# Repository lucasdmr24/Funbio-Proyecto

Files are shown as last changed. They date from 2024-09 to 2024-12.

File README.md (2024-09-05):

¡Bienvenido al repositorio del grupo 4 del horario B403 de Fundamentos de Biondiseño!

Integrantes:
- **Lucas Daniel Mendoza Ramos** (Rol: Coordinador General y GitHub), estudiante de 4to ciclo de Ingeniería Biomédica interesado en desarrollo de equipos médicos e investigación. Descripción del rol: Organizar y gestionar reuniones grupales y documentos; gestión principal del repositorio de github así como la organización de tareas e información para el producto a deseñar.

  Foto Lucas (1)

- **Massiel Melisa Badillo Aguayo** (Rol: Diseño 3D y Investigación), estudiante de 4to ciclo de Ingeniería Biomédica interesada en ingeniería de tejidos y rehabilitación de pacietes. Descripción del rol: Plasmar la propuesta de solución grupal en un programa que permita su modelamiento 3D para una posterior impresión o ensamblamiento. 

  massiel foto (1)

- **Pablo Emilio Parra Valer** (Rol: Prototipado Electrónico y Actualización del Git), estudiante de 4to ciclo de Ingeniería Biomédica interesado en diseño de prótesis y desarrollo de equipos médicos. Descripción del rol: Actualizar constantemente el repositorio por medio de github; gestionar el trabajo necesario en el ámbito electrónico para su implementación en el diseño 3D.
  
  parra foto

- **Ariana Valentina Ninanya Cruz** ( Rol: Manufactura Digital y Investigación), estudiante de 4to ciclo de Ingeniería Biomédica con principal interés en la gestión de biomateriales para la producción de prótesis de rehabilitación. Descripción del rol: Gestión de materiales necesarios para la el ensamble del prototipo, encargada principal del proceso de impresión y ensamble.

  ariana foto (1)

- **Maria Teresa Mone Vilchez** (Rol: Diseño Electrónico y Redacción), estudiante de 4to ciclo de Ingeniería Biomédica interesada principalmente en ingeniería clínica y rehabilitación. Descripción del rol: Trabajo dentro de la programación del código para el circuito electrónico y funcionabilidad del mismo en una etapa posterior. 

  tere foto (1)

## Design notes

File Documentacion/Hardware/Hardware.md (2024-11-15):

*Planos case MPU superior e inferior:*

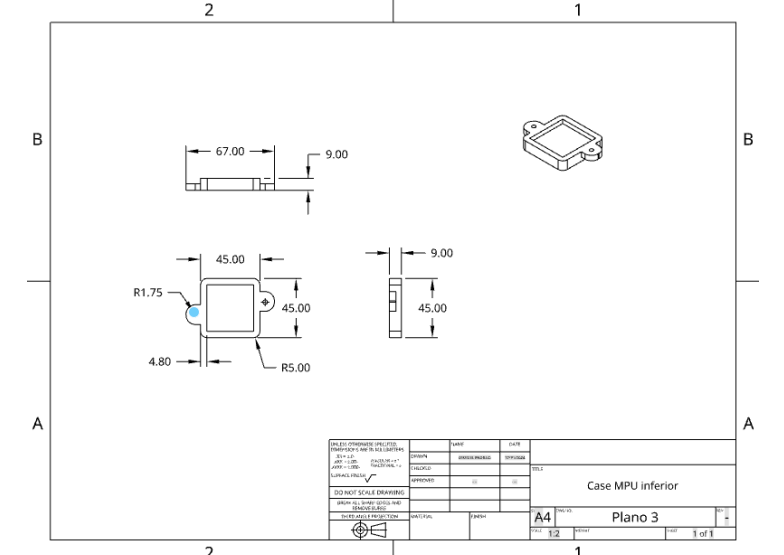
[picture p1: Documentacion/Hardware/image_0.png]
image alt text


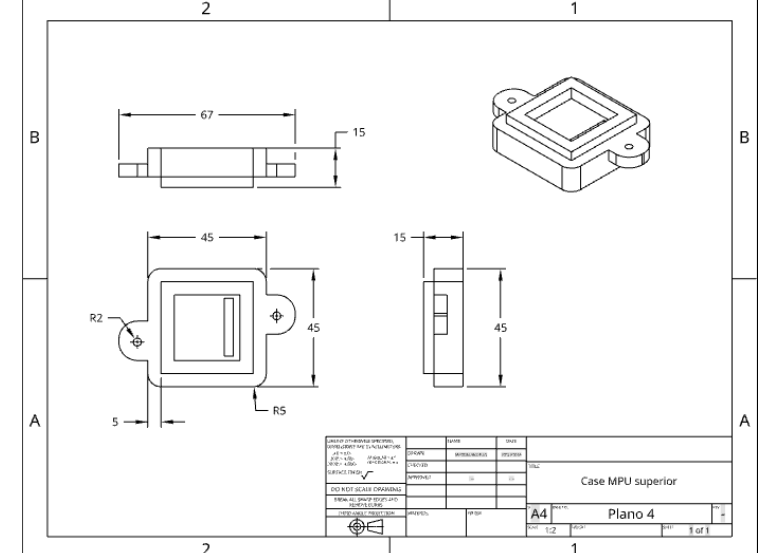
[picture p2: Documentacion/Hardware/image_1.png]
image alt text


*Planos para el case de los demás componentes electrónicos:*

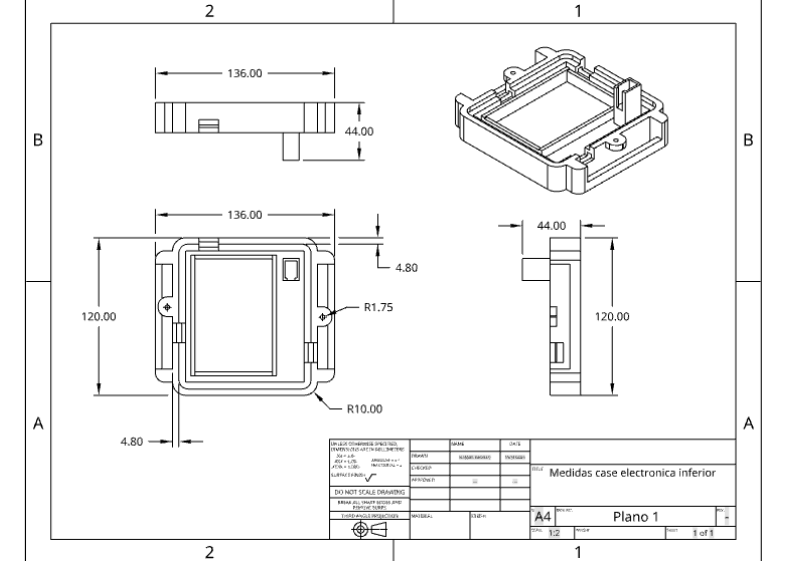
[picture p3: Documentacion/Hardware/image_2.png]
image alt text


image alt text

*Plano para case del portapila:*

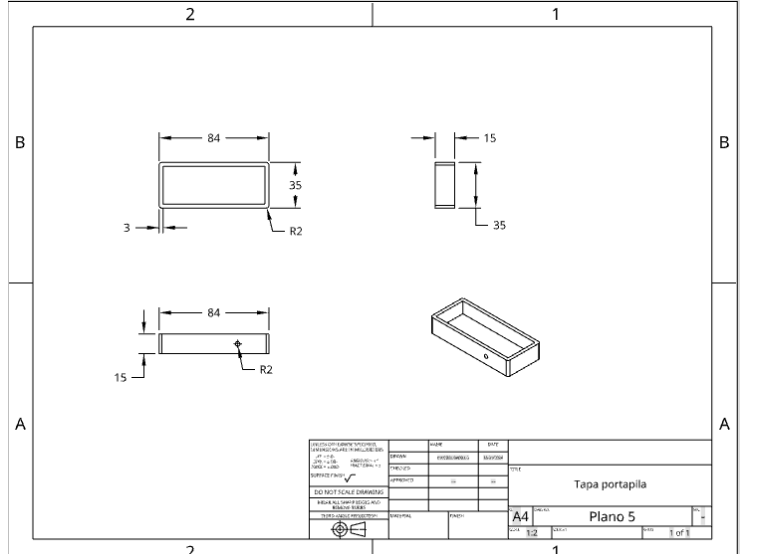
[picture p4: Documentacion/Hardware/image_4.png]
image alt text


*Ensamble:*

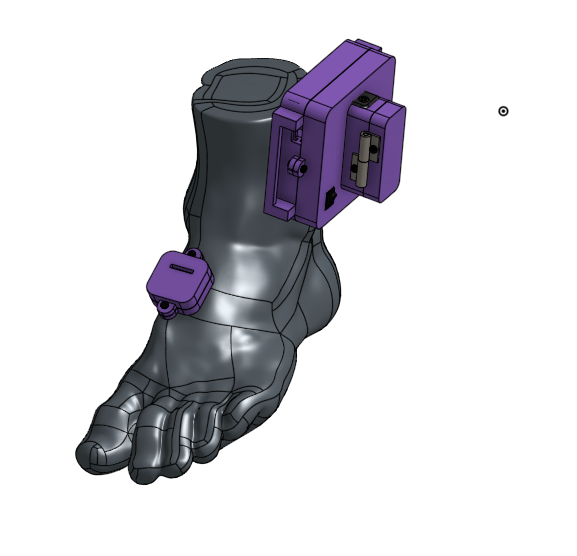
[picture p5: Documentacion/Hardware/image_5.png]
image alt text


ONESHOPE:
[https://cad.onshape.com/documents/b59706230b3147a766a9d8ca/w/d9faae820f9fd83e4ae611a1/e/5ab465d6ad715a8f3c73b799](https://cad.onshape.com/documents/b59706230b3147a766a9d8ca/w/d9faae820f9fd83e4ae611a1/e/5ab465d6ad715a8f3c73b799)

*Esquema Electrónico *

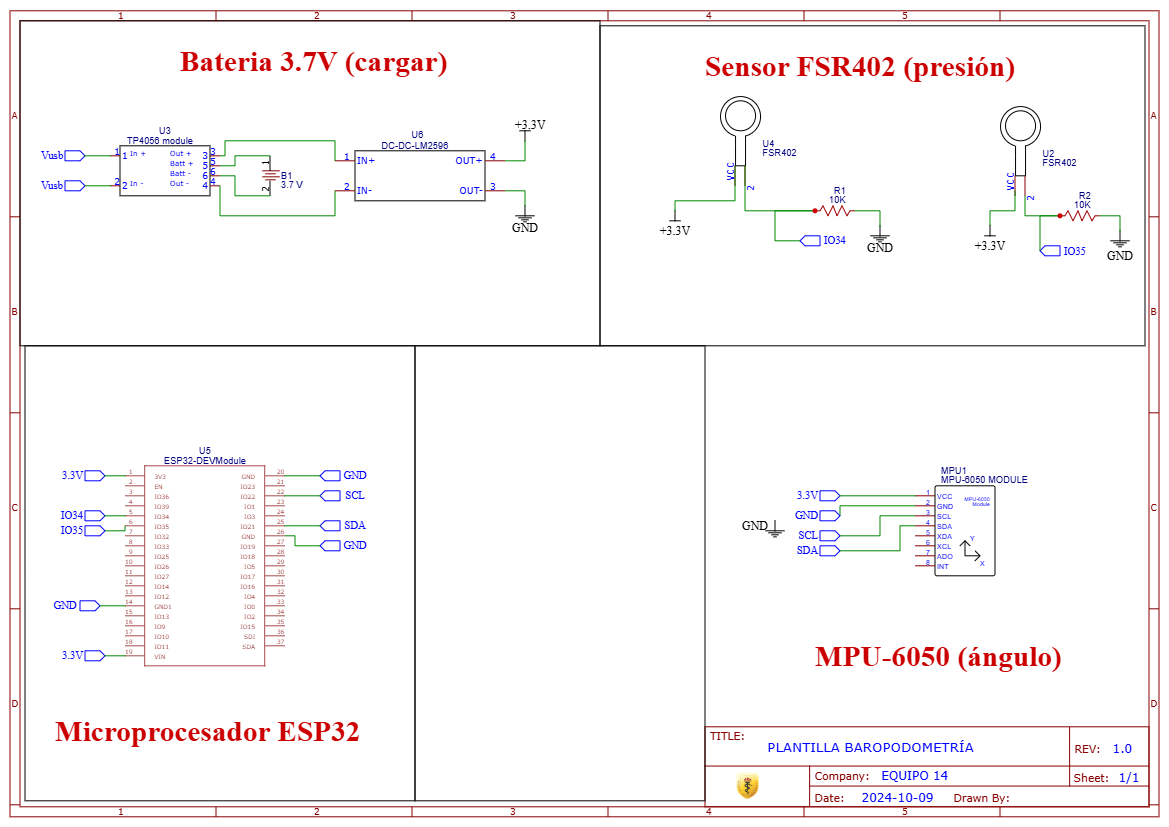
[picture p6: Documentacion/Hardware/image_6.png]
image alt text


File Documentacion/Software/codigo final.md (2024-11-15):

#include <Adafruit_MPU6050.h>

#include <Adafruit_Sensor.h>

#include <Wire.h>

#define FORCE_SENSOR_PIN 35 // ESP32 pin GIOP35 (ADC1)

#define FORCE_SENSOR_PIN2 34 // ESP32 pin GIOP34 (ADC1)

Adafruit_MPU6050 mpu;

// Variables para almacenar los valores iniciales de calibración

float initialAccelX = 0.0, initialAccelY = 0.0, initialAccelZ = 0.0;

float initialGyroX = 0.0, initialGyroY = 0.0, initialGyroZ = 0.0;

// Variables para el control de tiempo con millis()

unsigned long lastForceSensorReadTime = 0;

unsigned long lastForceSensorReadTime2 = 0;

unsigned long lastCalibrationTime = 0;

unsigned long lastMpuEventTime = 0;

// Intervalos de tiempo

const unsigned long forceSensorInterval = 1000; // Intervalo para la lectura de los sensores de fuerza

const unsigned long calibrationInterval = 10; // Intervalo durante la calibración

const unsigned long mpuEventInterval = 100; // Intervalo para la lectura del MPU6050

void setup() {

  Serial.begin(115200);

  // Inicialización de MPU6050

  pinMode(4, OUTPUT);

  while (!Serial) delay(10); // Espera hasta que el puerto serie esté disponible

  Serial.println("Adafruit MPU6050 test!");

  if (!mpu.begin()) {

    Serial.println("Failed to find MPU6050 chip");

    while (1) {

      delay(10);

    }

  }

  Serial.println("MPU6050 Found!");

  mpu.setAccelerometerRange(MPU6050_RANGE_8_G);

  mpu.setGyroRange(MPU6050_RANGE_500_DEG);

  mpu.setFilterBandwidth(MPU6050_BAND_5_HZ);

  // Calibración inicial y almacenar los valores base

  Serial.println("Calibrating accelerometer and gyroscope...");

  calibrateMPU();

  Serial.println("Calibration complete.");

  // Configurar el ADC para los sensores de fuerza

  pinMode(FORCE_SENSOR_PIN, INPUT);

  pinMode(FORCE_SENSOR_PIN2, INPUT);

}

void loop() {

  unsigned long currentMillis = millis();

  // Lectura y procesamiento del MPU6050 a intervalos regulares

  if (currentMillis - lastMpuEventTime >= mpuEventInterval) {

    lastMpuEventTime = currentMillis;

    sensors_event_t a, g, temp;

    mpu.getEvent(&a, &g, &temp);

    float deltaAccelX = a.acceleration.x - initialAccelX;

    float deltaAccelY = a.acceleration.y - initialAccelY;

    float deltaAccelZ = a.acceleration.z - initialAccelZ;

    float deltaGyroX = g.gyro.x - initialGyroX;

    float deltaGyroY = g.gyro.y - initialGyroY;

    float deltaGyroZ = g.gyro.z - initialGyroZ;

    Serial.print("Cambio en Aceleracion X: ");

    Serial.print(deltaAccelX);

    Serial.print(", Y: ");

    Serial.print(deltaAccelY);

    Serial.print(", Z: ");

    Serial.print(deltaAccelZ);

    Serial.println(" m/s^2");

    Serial.print("Cambio en Rotacion X: ");

    Serial.print(deltaGyroX);

    Serial.print(", Y: ");

    Serial.print(deltaGyroY);

    Serial.print(", Z: ");

    Serial.print(deltaGyroZ);

    Serial.println(" rad/s");

    Serial.print("Temperatura: ");

    Serial.print(temp.temperature);

    Serial.println(" grados C");

    // Control de salida basado en temperatura

    if (temp.temperature > 31) {

      digitalWrite(4, HIGH);

    } else {

      digitalWrite(4, LOW);

    }

  }

  // Lectura y procesamiento de los sensores de fuerza a intervalos regulares

  if (currentMillis - lastForceSensorReadTime >= forceSensorInterval) {

    lastForceSensorReadTime = currentMillis;

    int analogReading = analogRead(FORCE_SENSOR_PIN);

    Serial.print("The force sensor value = ");

    Serial.print(analogReading);

    if (analogReading < 10) Serial.println(" -> no hay presion");

    else if (analogReading < 200) Serial.println(" -> presion baja");

    else if (analogReading < 500) Serial.println(" -> presion media");

    else if (analogReading < 800) Serial.println(" -> presion alta");

    else Serial.println(" -> presion muy alta");

  }

  if (currentMillis - lastForceSensorReadTime2 >= forceSensorInterval) {

    lastForceSensorReadTime2 = currentMillis;

    int analogReading2 = analogRead(FORCE_SENSOR_PIN2);

    Serial.print("The force sensor2 value = ");

    Serial.print(analogReading2);

    if (analogReading2 < 10) Serial.println(" -> no hay presion");

    else if (analogReading2 < 200) Serial.println(" -> presion baja");

    else if (analogReading2 < 500) Serial.println(" -> presion media");

    else if (analogReading2 < 800) Serial.println(" -> presion alta");

    else Serial.println(" -> presion muy alta");

  }

}

// Función de calibración para el MPU6050 usando millis()

void calibrateMPU() {

  long accelSumX = 0, accelSumY = 0, accelSumZ = 0;

  long gyroSumX = 0, gyroSumY = 0, gyroSumZ = 0;

  unsigned long calibrationStartTime = millis();

  int calibrationSamples = 100;

  int sampleCount = 0;

  while (sampleCount < calibrationSamples) {

    unsigned long currentMillis = millis();

    if (currentMillis - lastCalibrationTime >= calibrationInterval) {

      lastCalibrationTime = currentMillis;

      sensors_event_t a, g, temp;

      mpu.getEvent(&a, &g, &temp);

      accelSumX += a.acceleration.x;

      accelSumY += a.acceleration.y;

      accelSumZ += a.acceleration.z;

      gyroSumX += g.gyro.x;

      gyroSumY += g.gyro.y;

      gyroSumZ += g.gyro.z;

      sampleCount++;

    }

  }

  initialAccelX = accelSumX / (float)calibrationSamples;

  initialAccelY = accelSumY / (float)calibrationSamples;

  initialAccelZ = accelSumZ / (float)calibrationSamples;

  initialGyroX = gyroSumX / (float)calibrationSamples;

  initialGyroY = gyroSumY / (float)calibrationSamples;

  initialGyroZ = gyroSumZ / (float)calibrationSamples;

}

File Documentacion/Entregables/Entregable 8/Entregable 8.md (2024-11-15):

**1. Introducción y Contextualización del Prototipo**

**Descripción del proyecto:**

El producto se basa en un sistema de sensores tanto de presión como de ángulo con el fin de llevar a cabo un monitoreo respecto a esos parámetros de la pisada de un paciente con amputación, puesto que estos valores se ven afectados tras este tipo de casos; ya sea aumentando el desequilibrio o reduciendo la movilidad de ángulo de la extremidad sana. Es decir, el proyecto está enfocado en la parte posterior a la entrega de la prótesis del paciente (seguimiento).

**Problemática abordada:**

Las amputaciones son más frecuentes en adultos mayores, los cuales representan alrededor del 45% de la población con pérdida de extremidades. Como consecuencia de una amputación, el centro de masa se ve afectado y altera significativamente el equilibrio al caminar. Las amputaciones de miembros inferiores (AK) en pacientes con diabetes mellitus afectan gravemente su calidad de vida, tanto física como emocionalmente, dificultando su reintegración social y laboral. La supervisión inadecuada durante la fase prostética puede causar complicaciones físicas, como debilidad muscular y deformidades, aumentando la dependencia de la extremidad sana. Esto también afecta psicológicamente al paciente, retrasando su recuperación. 

**Objetivos de la fase de integración:**

Se espera que a través de este proyecto los parámetros de presión plantar y ángulo de progresión de marcha logren ser medidos simultáneamente y desde un lugar que no sea necesariamente un establecimiento de salud, sino que pueda ser usado por el paciente independientemente.

**2. Componentes del prototipo**

Para comprender la función de cada componente, primero se elaboró un esquema de funciones donde se describen las funciones principales que busca el proyecto.

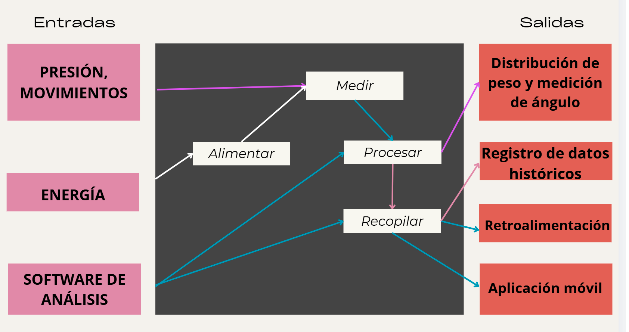
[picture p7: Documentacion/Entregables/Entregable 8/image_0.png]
image alt text


Con este esquema, se lograron identificar los componentes principales para llevar a cabo los requerimientos funcionales y no funcionales:

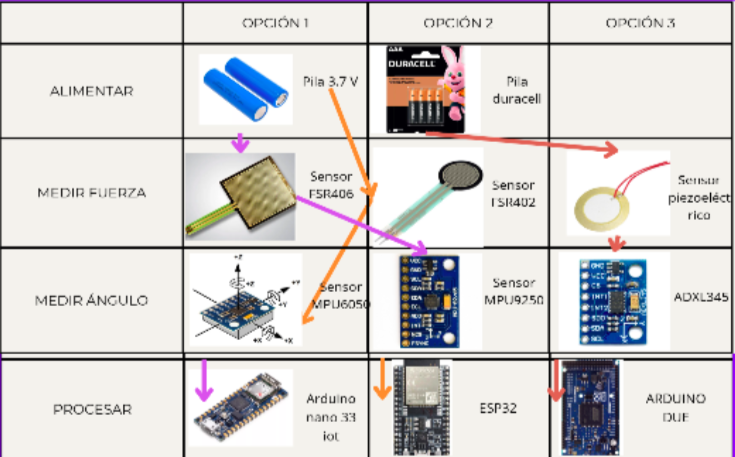
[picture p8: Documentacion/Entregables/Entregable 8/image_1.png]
image alt text


(Tras una evaluación en base a criterios de funcionalidad se escogió la opción 1)

Para poder describir la interacción entre los componentes, se procedió a realizar un esquemático electrónico: 

image alt text

**3, ****Proceso de Integración**

**Plan de integración:**

Tras tener las funciones establecidas, se procedió a identificar cómo irían conectados los componentes necesarios y cómo se deben distribuir para cumplir su función. Tomando en cuenta esto, se procedió a identificar 3 modelos importantes en el 3D para nuestro proyecto: un case para el MPU, uno para el resto de componentes electrónicos y una tapa para el portapila. A continuación, se muestran los planos, el ensamble y el link del onshape: [https://cad.onshape.com/documents/b59706230b3147a766a9d8ca/w/d9faae820f9fd83e4ae611a1/e/5ab465d6ad715a8f3c73b799](https://cad.onshape.com/documents/b59706230b3147a766a9d8ca/w/d9faae820f9fd83e4ae611a1/e/5ab465d6ad715a8f3c73b799)

*Planos case MPU superior e inferior:*

image alt text

image alt text

*Planos para el case de los demás componentes electrónicos:*

image alt text

image alt text

*Plano para case del portapila:*

image alt text

*Ensamble:*

image alt text

**_Observaciones (Desafíos y ajustes realizados):_**

* Las piezas se encuentran en cola para imprimir, los planos han sido aprobados.

* La corrección de los planos respecto al anterior entregable se basa principalmente en los bordes de las piezas, de manera que se añadieron fillets.

* El objetivo principal de este diseño es la portabilidad y la comodidad del usuario al usar el dispositivo (por lo que no se usan demasiadas piezas) con el fin que sea fácil de poner y sacar.

* La unión está planeada con un velcro, de manera que simule una tobillera.

**_Revisión de compatibilidad y sincronización:_**

**Aún no realizó la prueba de compatibilidad por el cierre de la universidad por esta semana ****_
_**

**4. Pruebas y Verificación:**

**Descripción de pruebas funcionales:**

Primero se armó el circuito de cada sensor por separado comenzando con el acelerómetro.

MPU6050

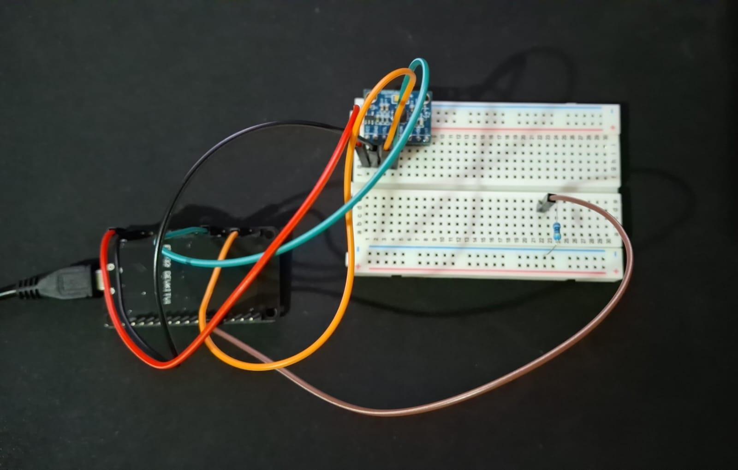
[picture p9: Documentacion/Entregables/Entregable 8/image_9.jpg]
image alt text


**
**

Al principio se quería medir el cambio de ángulo de inclinación respecto a un punto inicial guardado pero esto no era posible, así que optamos por cambiar eso y medir el cambio de posición respecto a un punto guardado así obtendremos que tan preciso es el recorrido de las pisadas, también añadimos un giroscopio que medirá el cambio constante del ángulo que en teoría debería ser de baja variación (se harán las pruebas respectivas después para tener con qué datos comparar). 

Después teníamos que  calibrar el MPU6050 y cambiar parámetros como el "delay" a “millis” para tener un monitoreo más continuo y sin cortes 

Después armamos el circuito del FSR402

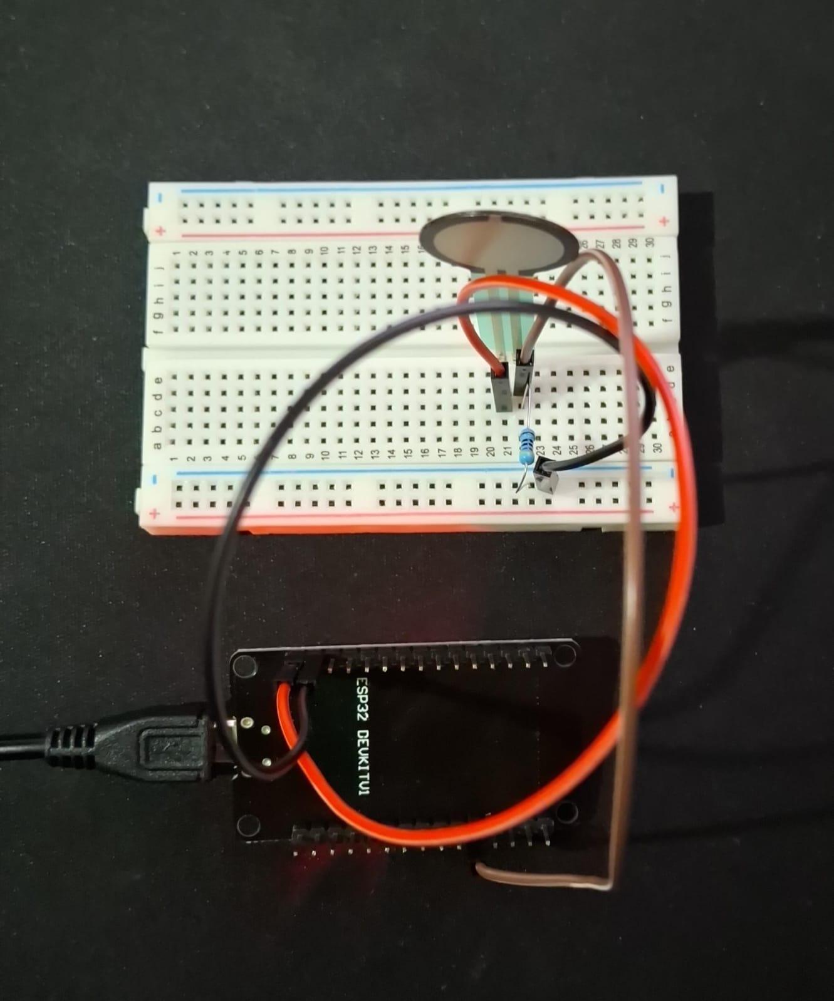
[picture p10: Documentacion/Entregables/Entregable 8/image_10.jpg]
image alt text


Después añadimos un segundo FSR402 (ambos FSR402 están conectados a entradas ADC en este paso D34 y D35) y duplicamos el código modificando las definiciones del sensor como "FSR402_1" y segundo el añadido como “FSR402_2”.

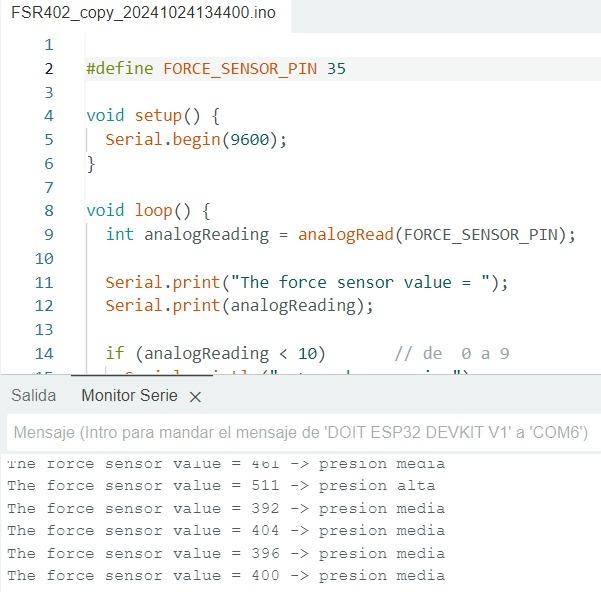
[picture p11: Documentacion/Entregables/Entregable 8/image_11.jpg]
image alt text


Prueba de 1 FSR402

Al final juntamos todo el circuito cambiando el código de delay a millis y ajustando los printf

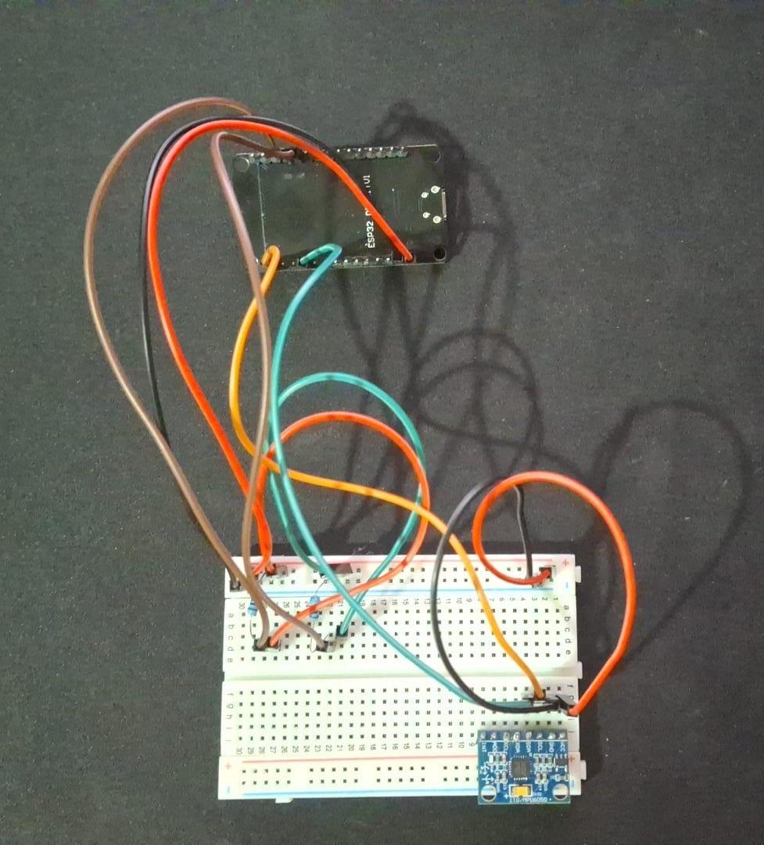
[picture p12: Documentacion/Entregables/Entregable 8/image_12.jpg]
image alt text


Código Final:

[https://github.com/lucasdmr24/Funbio-Proyecto/blob/main/Documentacion/Software/codigo%20final.md](https://github.com/lucasdmr24/Funbio-Proyecto/blob/main/Documentacion/Software/codigo%20final.md)

**5. Conclusiones y Próximos Pasos **

**Resumen de Logros**

* Aprobación de los modelados 3D de las piezas a imprimir.

* Los componentes electrónicos se han unido en simultáneo y funcionan adecuadamente.

* El código está completado y los datos se pueden medir en tiempo real.

* Se puede visualizar la fluctuación de los datos en una gráfica que varía en tiempo real de acuerdo al cambio de los datos.

**Aspectos a Mejorar**

* Aún requerimos de las partes 3d en físico para hacer pruebas finales además de buscar una tobillera que cumple los requisitos de nuestro sistema.

* También falta añadir el TP4056 que adquirimos hace poco y un botón switch. Luego cambiar el circuito de prototipo a uno final cambiando los jumpers con cables de calibre 24 

**Siguientes fases del desarrollo **

* Imprimir los componentes 3D y verificar que estos se hayan impreso de manera correcta.

* Realizar el circuito final junto con los cambios en los componentes que sean necesarios.

* Acoplar el circuito final junto con los componentes 3D para realizar pruebas con el prototipo ya completamente ensamblado.

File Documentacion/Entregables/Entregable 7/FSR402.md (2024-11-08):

#define FORCE_SENSOR_PIN 35 // ESP32 pin GIOP35 (ADC1):

void setup() {

  Serial.begin(9600);

}

void loop() {

  int analogReading = analogRead(FORCE_SENSOR_PIN);

  Serial.print("The force sensor value = ");

  Serial.print(analogReading); // print the raw analog reading

  if (analogReading < 10)       // from 0 to 9

    Serial.println(" -> no hay presion");

  else if (analogReading < 200) // from 10 to 199

    Serial.println(" -> presion baja ");

  else if (analogReading < 500) // from 200 to 499

    Serial.println(" -> presion media ");

  else if (analogReading < 800) // from 500 to 799

    Serial.println(" -> presion alta");

  else // from 800 to 1023

    Serial.println(" -> presion muy alta");

  delay(100);

}

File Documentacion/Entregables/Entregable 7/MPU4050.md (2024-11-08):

#include <Adafruit_MPU6050.h>

#include <Adafruit_Sensor.h>

#include <Wire.h>

Adafruit_MPU6050 mpu;

void setup(void) {

  Serial.begin(115200);

  pinMode (4, OUTPUT);

  while (!Serial)

    delay(10);

  Serial.println("Adafruit MPU6050 test!");

  if (!mpu.begin()) {

    Serial.println("Failed to find MPU6050 chip");

    while (1) {

      delay(10);

    }

  }

  Serial.println("MPU6050 Found!");

  mpu.setAccelerometerRange(MPU6050_RANGE_8_G);

  Serial.print("Accelerometer range set to: ");

  switch (mpu.getAccelerometerRange()) {

  case MPU6050_RANGE_2_G:

    Serial.println("+-2G");

    break;

  case MPU6050_RANGE_4_G:

    Serial.println("+-4G");

    break;

  case MPU6050_RANGE_8_G:

    Serial.println("+-8G");

    break;

  case MPU6050_RANGE_16_G:

    Serial.println("+-16G");

    break;

  }

  mpu.setGyroRange(MPU6050_RANGE_500_DEG);

  Serial.print("Gyro range set to: ");

  switch (mpu.getGyroRange()) {

  case MPU6050_RANGE_250_DEG:

    Serial.println("+- 250 deg/s");

    break;

  case MPU6050_RANGE_500_DEG:

    Serial.println("+- 500 deg/s");

    break;

  case MPU6050_RANGE_1000_DEG:

    Serial.println("+- 1000 deg/s");

    break;

  case MPU6050_RANGE_2000_DEG:

    Serial.println("+- 2000 deg/s");

    break;

  }

  mpu.setFilterBandwidth(MPU6050_BAND_5_HZ);

  Serial.print("Filter bandwidth set to: ");

  switch (mpu.getFilterBandwidth()) {

  case MPU6050_BAND_260_HZ:

    Serial.println("260 Hz");

    break;

  case MPU6050_BAND_184_HZ:

    Serial.println("184 Hz");

    break;

  case MPU6050_BAND_94_HZ:

    Serial.println("94 Hz");

    break;

  case MPU6050_BAND_44_HZ:

    Serial.println("44 Hz");

    break;

  case MPU6050_BAND_21_HZ:

    Serial.println("21 Hz");

    break;

  case MPU6050_BAND_10_HZ:

    Serial.println("10 Hz");

    break;

  case MPU6050_BAND_5_HZ:

    Serial.println("5 Hz");

    break;

  }

  Serial.println("");

  delay(100);

}

void loop() {

  sensors_event_t a, g, temp;

  mpu.getEvent(&a, &g, &temp);

  Serial.print("Acceleracion X: ");

  Serial.print(a.acceleration.x);

  Serial.print(", Y: ");

  Serial.print(a.acceleration.y);

  Serial.print(", Z: ");

  Serial.print(a.acceleration.z);

  Serial.println(" m/s^2");

  Serial.print("Rotacion X: ");

  Serial.print(g.gyro.x);

  Serial.print(", Y: ");

  Serial.print(g.gyro.y);

  Serial.print(", Z: ");

  Serial.print(g.gyro.z);

  Serial.println(" rad/s");

  Serial.print("Temperatura: ");

  Serial.print(temp.temperature);

  Serial.println(" grados C");

  Serial.println("");

  delay(100);

  if (temp.temperature > 31){

    digitalWrite(4, HIGH);

  }

  else{

    digitalWrite(4, LOW);

  }

}

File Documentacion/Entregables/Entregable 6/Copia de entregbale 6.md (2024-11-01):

Modelado 3D  

Diseño en onshape ensamblado: 

[https://cad.onshape.com/documents/b59706230b3147a766a9d8ca/w/d9faae820f9fd83e4ae611a1/e/01ad5f6915a1a5d2a1a74f02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](https://cad.onshape.com/documents/b59706230b3147a766a9d8ca/w/d9faae820f9fd83e4ae611a1/e/01ad5f6915a1a5d2a1a74f02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)

Diseño en sketchfab: 

[https://skfb.ly/p8uXs](https://skfb.ly/p8uXs)

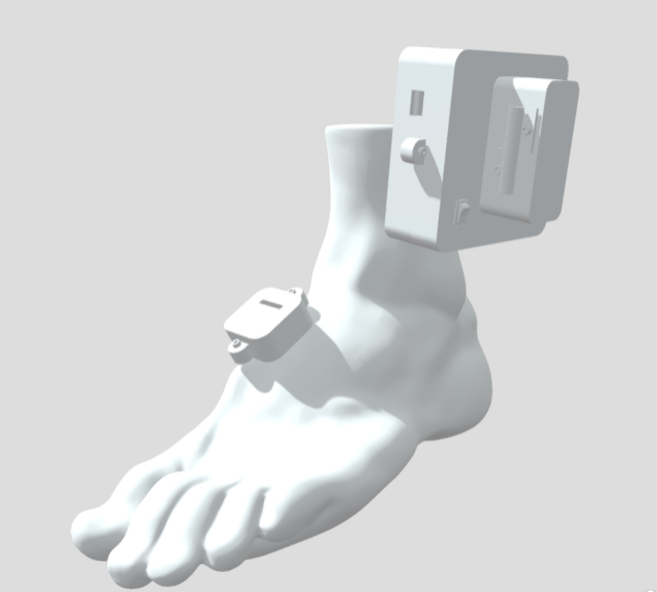
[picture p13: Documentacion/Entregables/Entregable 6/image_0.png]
image alt text


Plano de materiales y electronicos a usar: 

[https://cad.onshape.com/documents/b59706230b3147a766a9d8ca/w/d9faae820f9fd83e4ae611a1/e/3d03eb26edddc29ad61f9a50](https://cad.onshape.com/documents/b59706230b3147a766a9d8ca/w/d9faae820f9fd83e4ae611a1/e/3d03eb26edddc29ad61f9a50)

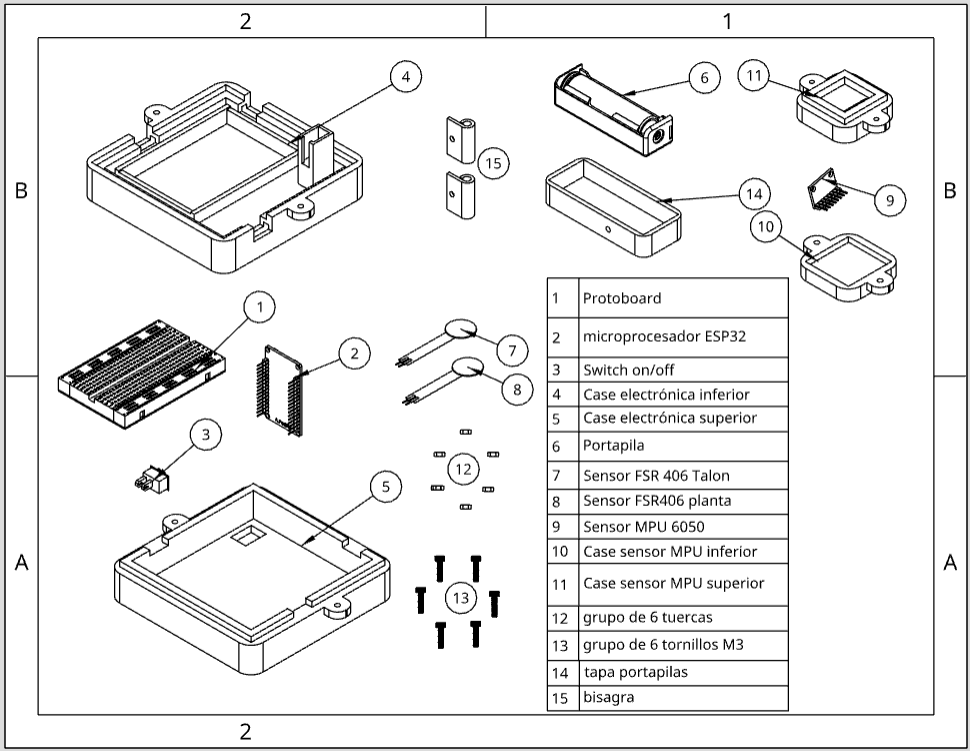
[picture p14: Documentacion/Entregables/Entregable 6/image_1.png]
image alt text


Vista explosionada: 

[https://cad.onshape.com/documents/b59706230b3147a766a9d8ca/w/d9faae820f9fd83e4ae611a1/e/c8d9c10dc0672cda1a7d5a13](https://cad.onshape.com/documents/b59706230b3147a766a9d8ca/w/d9faae820f9fd83e4ae611a1/e/c8d9c10dc0672cda1a7d5a13)

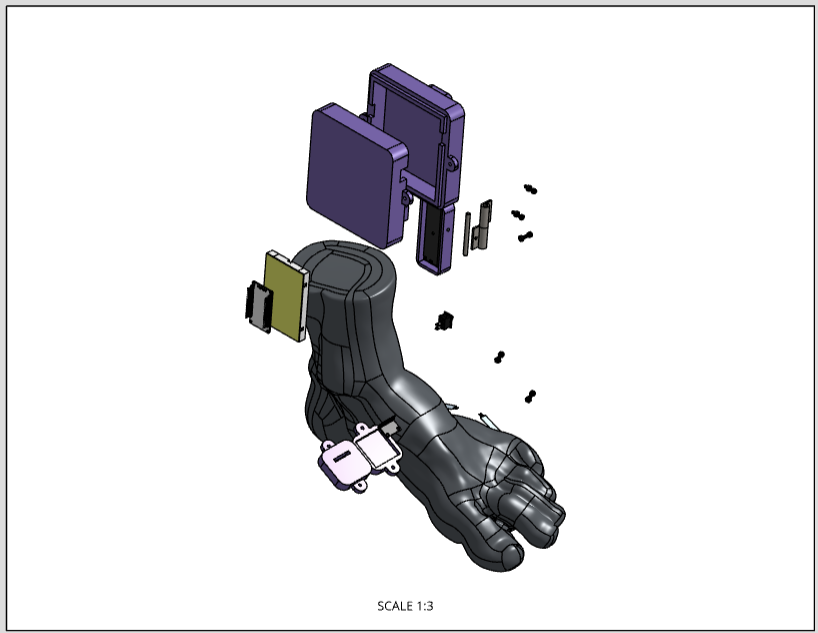
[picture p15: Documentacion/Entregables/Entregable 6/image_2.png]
image alt text


Plano 1: 

[https://cad.onshape.com/documents/b59706230b3147a766a9d8ca/w/d9faae820f9fd83e4ae611a1/e/08a3d7ae921a38b4f6f29460](https://cad.onshape.com/documents/b59706230b3147a766a9d8ca/w/d9faae820f9fd83e4ae611a1/e/08a3d7ae921a38b4f6f29460)

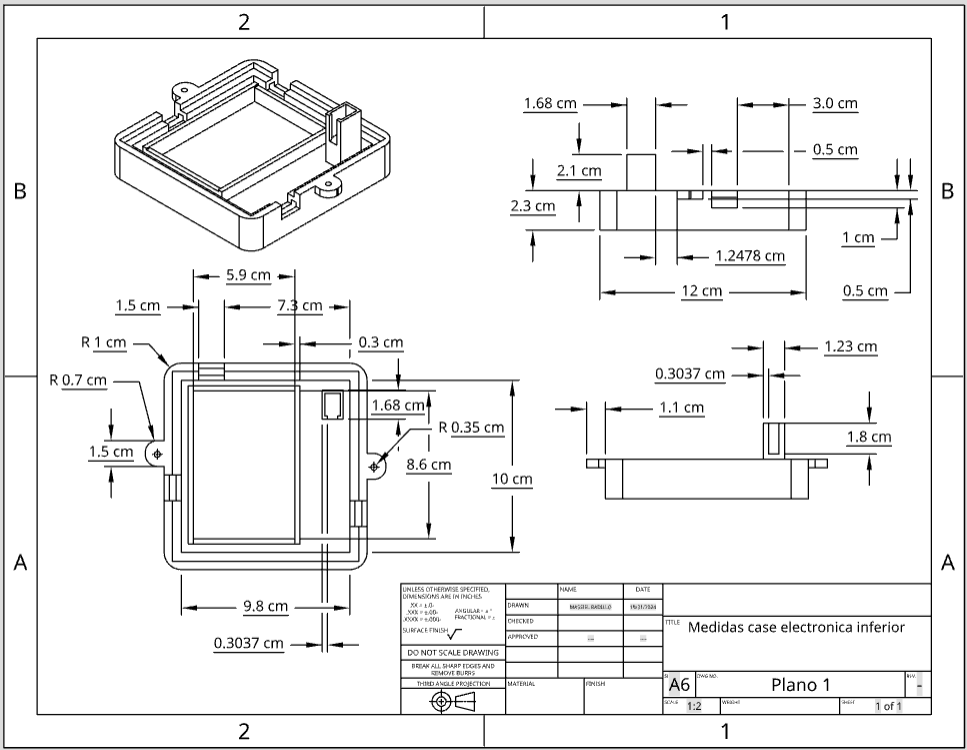
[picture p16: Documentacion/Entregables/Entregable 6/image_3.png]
image alt text


Plano 2:

[https://cad.onshape.com/documents/b59706230b3147a766a9d8ca/w/d9faae820f9fd83e4ae611a1/e/36dad9e3779bb2fee486169c](https://cad.onshape.com/documents/b59706230b3147a766a9d8ca/w/d9faae820f9fd83e4ae611a1/e/36dad9e3779bb2fee486169c)

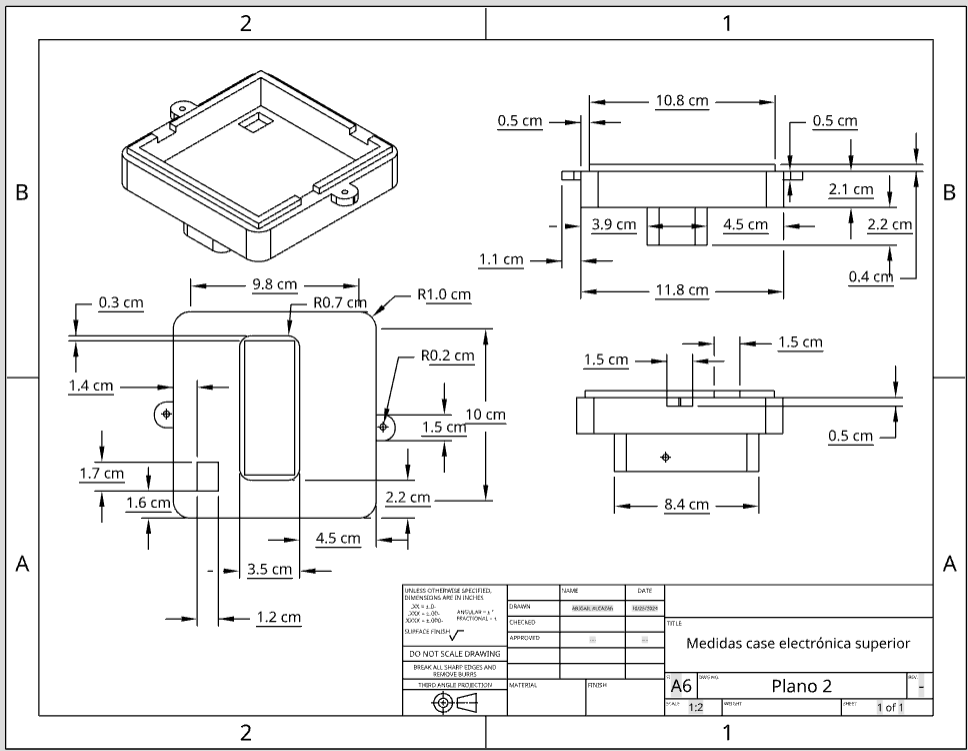
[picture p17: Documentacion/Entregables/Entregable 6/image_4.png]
image alt text


Plano 3: 

[https://cad.onshape.com/documents/b59706230b3147a766a9d8ca/w/d9faae820f9fd83e4ae611a1/e/b961a66d338589d1d2fa348e](https://cad.onshape.com/documents/b59706230b3147a766a9d8ca/w/d9faae820f9fd83e4ae611a1/e/b961a66d338589d1d2fa348e)

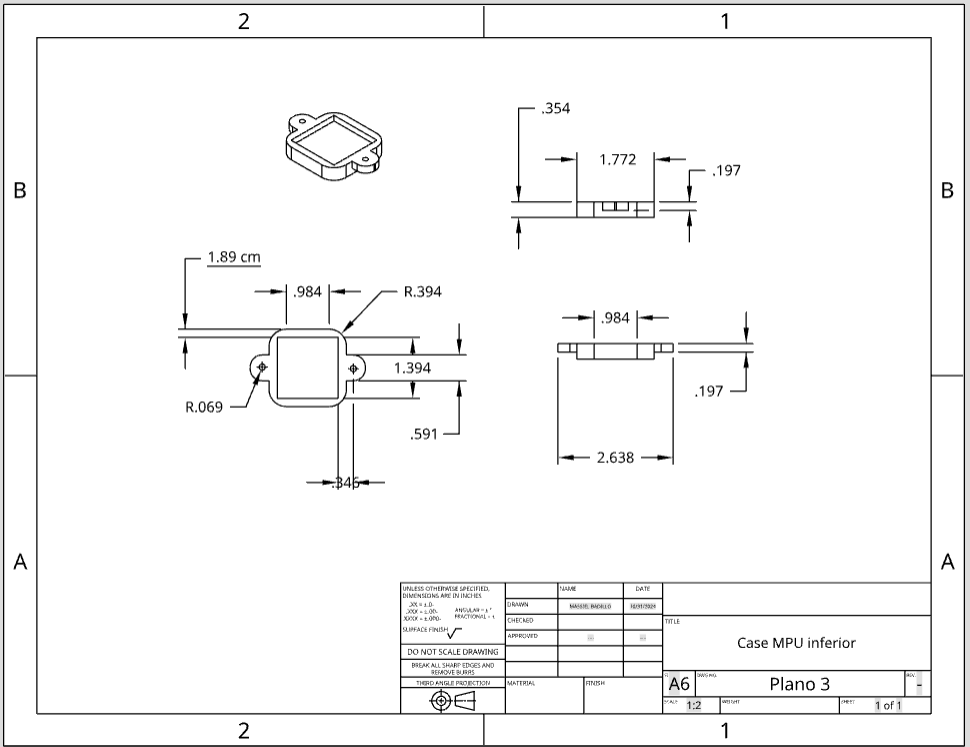
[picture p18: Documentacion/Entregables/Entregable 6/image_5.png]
image alt text


Plano 4:

[https://cad.onshape.com/documents/b59706230b3147a766a9d8ca/w/d9faae820f9fd83e4ae611a1/e/c9a6fd440dc8c1fb4327c2c3](https://cad.onshape.com/documents/b59706230b3147a766a9d8ca/w/d9faae820f9fd83e4ae611a1/e/c9a6fd440dc8c1fb4327c2c3)

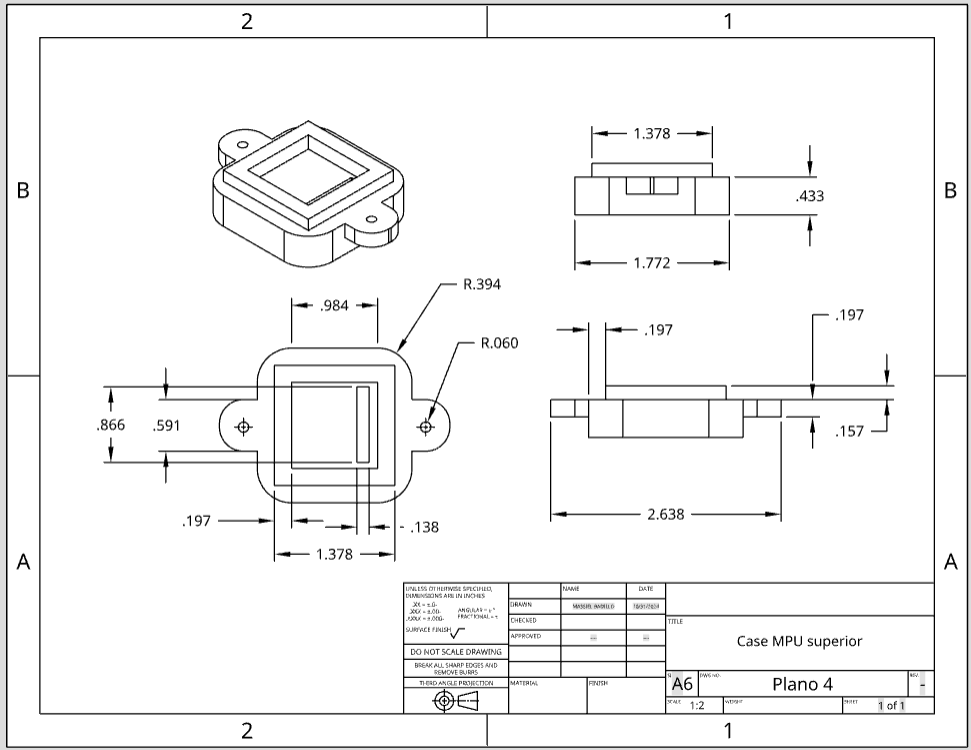
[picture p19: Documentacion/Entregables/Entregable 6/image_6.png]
image alt text


Plano 5:

[https://cad.onshape.com/documents/b59706230b3147a766a9d8ca/w/d9faae820f9fd83e4ae611a1/e/6f08b86290c640afea8cab9f](https://cad.onshape.com/documents/b59706230b3147a766a9d8ca/w/d9faae820f9fd83e4ae611a1/e/6f08b86290c640afea8cab9f)

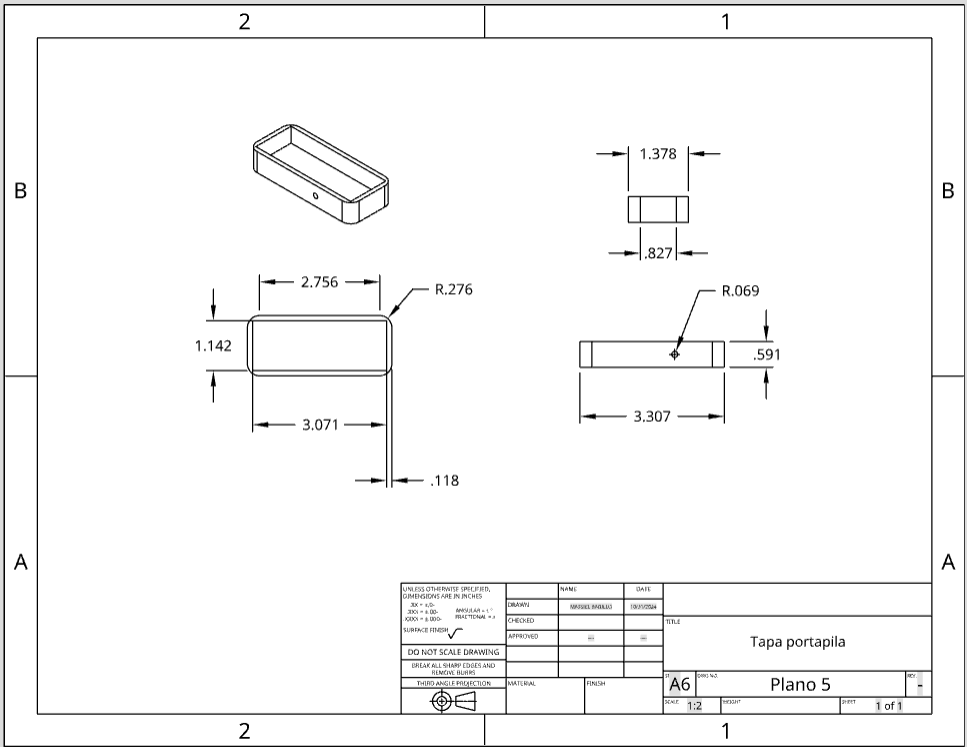
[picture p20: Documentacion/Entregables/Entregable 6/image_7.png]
image alt text


Esquemático electrónico:

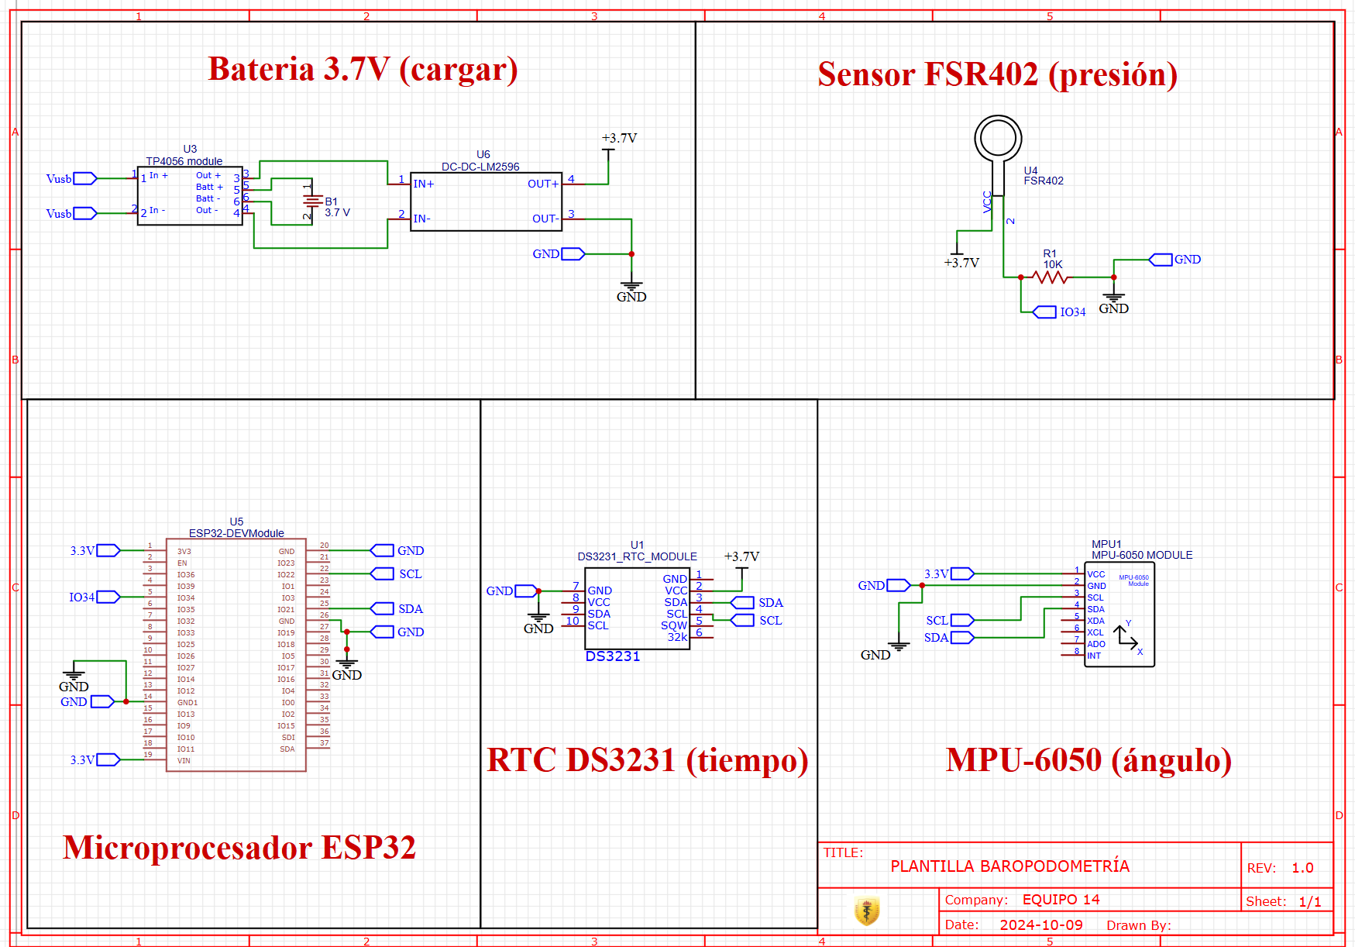
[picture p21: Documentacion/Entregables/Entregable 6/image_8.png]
image alt text


Electrónica

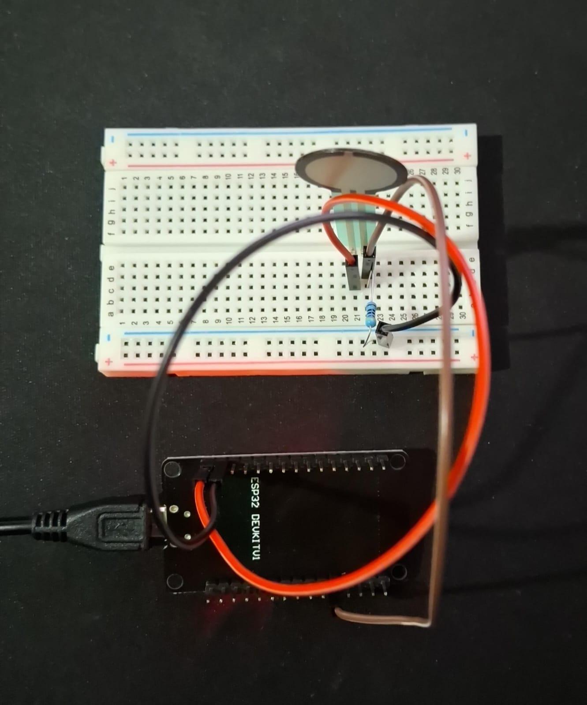
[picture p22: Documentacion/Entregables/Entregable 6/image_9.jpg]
image alt text
 

Programación: 
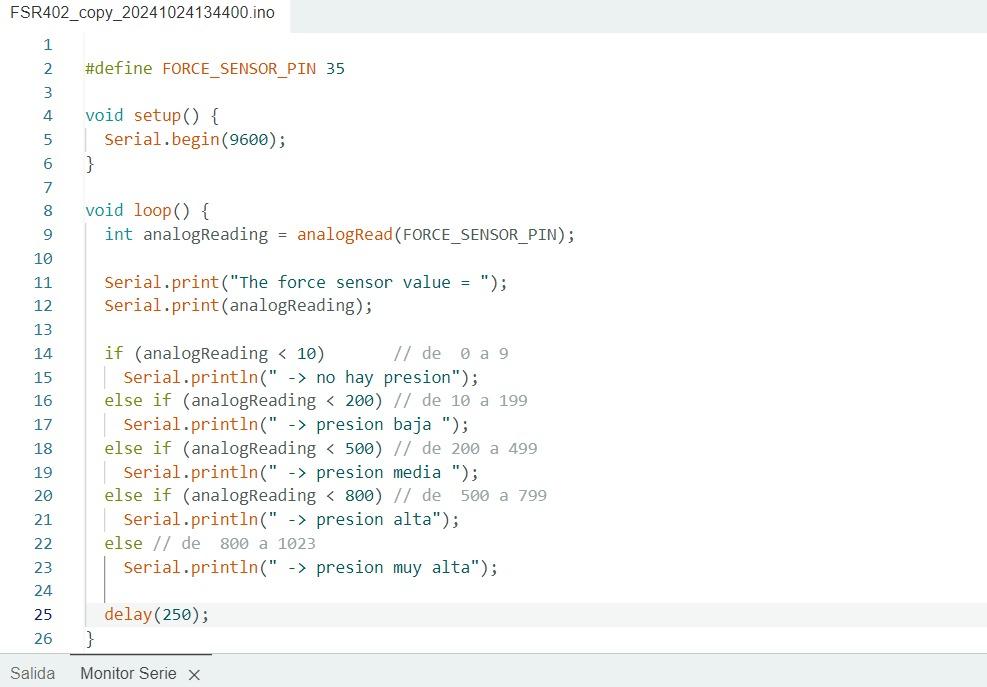
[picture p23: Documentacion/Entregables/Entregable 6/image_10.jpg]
image alt text


Monitor serie del código: 

image alt text

Gráfica de los valores obtenido en t:

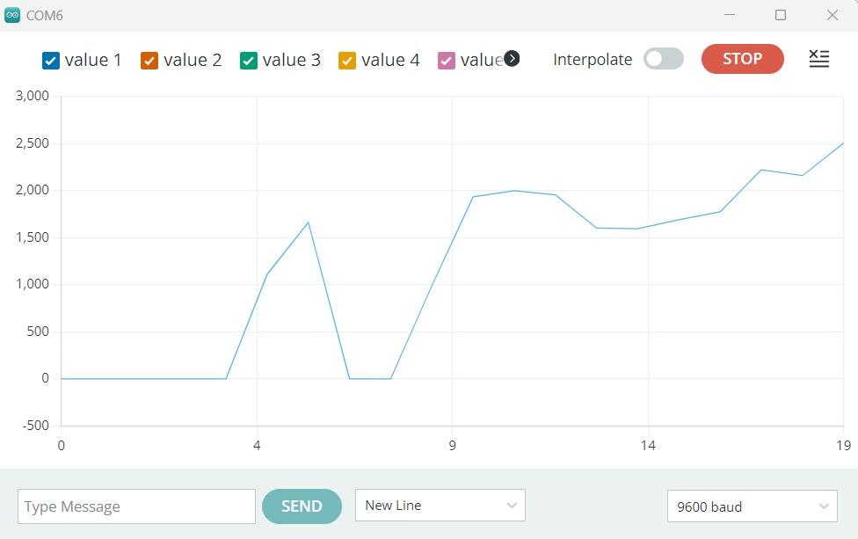
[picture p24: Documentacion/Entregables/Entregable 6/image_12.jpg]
image alt text


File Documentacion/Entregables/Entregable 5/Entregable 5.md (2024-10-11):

Diagrama o esquema electrónico el concepto de solución:

image alt text

Modelado 3D de los componentes por separado

Modelo ESP32 importado en onshape:

Importado en sketch: https://skfb.ly/prHzC

image alt text

Modelo sensor MPU6050 importado en onshape:

Importado en sketch: https://skfb.ly/prHzE

image alt text

Modelo Batería de Litio importado en onshape:

Importado en sketch: https://skfb.ly/prHzJ

image alt text

Modelo sensor FSR402 importado en onshape:

Importado en sketch: https://skfb.ly/prHzL

image alt text

Modelo sensor RTC DS3231 importado en onshape:

Importado en sketch: https://skfb.ly/prHzO

image alt text

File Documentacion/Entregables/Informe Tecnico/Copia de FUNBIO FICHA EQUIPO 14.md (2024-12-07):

**Ficha de detalles de la invención**

<table>
  <tr>
    <td>Título de la invención:</td>
    <td>PreasurePro</td>
  </tr>
</table>

1. **DESCRIPCIÓN DEL PROBLEMA TÉCNICO**

Indique y describa cuál es el problema técnico (o los problemas técnicos) que busca resolver la invención. 

*Se considera problema técnico aquel aspecto técnico (estructura, configuración, entre otros), que antes de la invención no tenía solución o tenía soluciones distintas a la provista por la invención.*

*En caso de Diseño Industrial, omitir esta parte.*

El problema que se busca resolver específicamente es la comparación de datos de 2 extremidades en tiempo real. Cuando una persona sufre una amputación, el centro de masa tiende a desplazarse y a perjudicar la extremidad sana. Es por ello que es imprescindible contar con un dispositivo que permita la comparación entre ambos miembros y, poder finalmente ver que ambos valores de presiones o fuerzas ejercidas sean similares; de lo contrario, el paciente podría estar sujeto a otras complicaciones médicas. De esta misma manera, se busca obtener datos como la medición de ángulo, puesto que cuando a una persona se le brinda una prótesis y durante ese proceso no se logra adaptar adecuadamente, su libertad de movimiento puede verse afectada. El ángulo de progresión de marcha es una medida que nos permite cuantificar la libertad con la que una extremidad se mueve, 

En pocas palabras, el producto busca brindar datos con el fin de acompañar al paciente amputado en el periodo prostético. Uno de los objetivos principales es poder aplicarlo al rubro de la telemedicina y que este sirva como un canal de comunicación/información entre el personal de salud y el paciente. De manera que mediante el almacenamiento y procesamiento de datos, se logre supervisar parámetros que afecten el día a día del paciente y con el fin principal de evitar la aparición de malestares sujetos al uso de la prótesis.

2. **DESCRIPCIÓN DETALLADA DEL INVENTO:**

Describa la invención de forma clara enfatizando en qué consiste el concepto inventivo central.

Si la invención es un producto, máquina, equipo y especifique sus partes y cómo se relacionan.

Si la invención es un procedimiento, especifique los pasos, parámetros de operación, insumos, o cualquier otra información relevante para alcanzar el efecto técnico. 

La invención puede tener el procedimiento y su producto novedosos por lo que puede detallar los dos. 

(Mínimo 250 palabras). *Incluya figuras, fotografías o diagramas.* *Adjunte a esta ficha todos las publicaciones u otros documentos asociados que posea al respecto*

En caso de Diseño Industrial, adjuntar imágenes o fotos del producto

El producto es un acoplamiento de ciertas piezas en uno solo. Consta de 2 cajas de soporte unidas a una tobillera; así como una caja de portapila. Dentro de estas cajas, se pueden encontrar los componentes electrónicos que permiten el funcionamiento del dispositivo.

En primer lugar, el dispositivo es alimentado por un voltaje que proviene de la batería (3.7 V), la cual está vinculada con un módulo de carga con el fin de ser recargable y evitar que el usuario esté cambiando constantemente de baterías. El dispositivo se prende a través de un botón switch que activa el sistema electrónico (protoboard,esp32,resistencias,sensores,etc). Asimismo, a través de bluetooth, se logra obtener las mediciones de los sensores en un dispositivo móvil.

image alt text

En la imagen se puede observar las 3 cajas mencionadas anteriormente y cómo estarían distribuidas en una extremidad sana. 

Los sensores que se han usado para la obtención de datos son 2 FSR402 (ubicados en la parte inferior de la planta del pie y los que miden presión plantar) y un MPU (medición de ángulo). Se integran los 3 sensores que se usan por extremidad son configurados para obtener los parámetros en tiempo real.

image alt text

En esta imagen se logra observar el prototipo una vez que los componentes han sido unificados y el circuito funciona correctamente, realizando y entregando los datos solicitados.

Como se observa en la imagen, los componentes, tanto los impresos 3D como los electrónicos han sido integrados finalmente en una tobillera. Esto se realizó con la finalidad de evitar el uso de muchas piezas por separado, lo cual puede inducir a una mayor confusión en el usuario o la tendencia a extraviar alguna pieza y afecte el funcionamiento del dispositivo.

3. **DESCRIPCIÓN DE LOS ANTECEDENTES**

Liste y describa los productos, procedimientos más parecidos a su proyecto y los principales antecedentes técnicos o bibliográficos que haya consultado. Explique cuáles fueron los principios técnicos en los que se inspiró para obtener la invención; o que usó y estudió durante el proceso de investigación que dio como origen al proyecto. Pueden ser papers, tesis, vídeos, documentos, libros, etc.

Para llegar a realizar este dispositivo, se tomó como referencia principal el estudio usado en la fisioterapia: baropodometría; la cual consiste principalmente en "el estudio biomecánico que mide las presiones plantares mientras el paciente camina o permanece de pie" Al cual se le añadió la medición de ángulo con el fin que el especialista pueda evaluar estos parámetros y compararlos. 

Se encontraron 2 principales productos que sirven como referencia para el desarrollo de este producto:

1. **Plataforma de presiones plantares: **

* Sistema de medición de presiones plantares que consta de una plataforma portátil.

* Ideal para identificar el tipo de pie según su apoyo.

* Muestra la distribución del peso del paciente en sus pies durante la marcha mientras incide en la plataforma o está en reposo.

* Peso: 4.5 kg

* Sensores Resistivos

image alt text

2. **XSENSOR in-shoe pressure measurement system: **

* Recopilación de datos en tiempo real

* Sensor de mapeo de presión plantar

* Detección dinámica inteligente permite un rendimiento elevado

* No se dobla bajo presión.

* No disponible en Perú

image alt text

Las características principales que encontramos en estos dispositivos radican principalmente en la medición de presiones plantares. Sin embargo, no se encontró un dispositivo que lo integre con la medición con sensor acelerómetro/giroscopio como el MPU y su respectiva integración por medio de un software a la telemedicina. La plataforma es usualmente puesta en uso para los exámenes de seguimiento al paciente de baropodometría.

.

    1. **¿Conoce algún trabajo o invento que se parece más a su invento? **Si la respuesta es afirmativa, enumerar, indicando el nombre de la publicación, la fuente y fecha de publicación y adjuntar un breve resumen de dicho antecedente.

Nombre de la publicación:  Analysis and detection system for abnormal pressure caused by diabetic sole lesion:

Fuente: 冯志宏. (2022). Analysis and detection system for abnormal pressure caused by diabetic sole lesion (Patent Núm. CN:114366079:A). En Patent (CN:114366079:A).

Fecha publicación:  2022-01-14

Se refiere a un sistema de análisis y detección de anomalías de presión causadas por lesiones de la planta diabética. Esta compensa los defectos de la placa plana de medición de fuerza y la plataforma de medición de fuerza a través del sistema de prueba de calzado y plantilla, puesto que en este sistema, se logra integrar directamente los sensores en áreas de posición correspondientes del zapato y la plantilla, de forma que puede recopilar datos dinámicos de presión plantar en el zapato y monitorea de forma continua y dinámica los parámetros de presión plantar de un sujeto durante mucho tiempo. También, los datos pueden ser transferidos al teléfono.

image alt text

    1. **Si Ud. ha identificado la existencia de un antecedente más cercano en el punto 3.1, señale cuáles son las características técnicas novedosas de su Invento en relación con dicho(s) antecedente(s). **De preferencia limite este comparativo solo a los tres antecedentes que considere más cercanos en el aspecto técnico y científico a su invención (el estado de la técnica).

El producto cuenta con varias diferencias. En primer lugar, la integración del sensor de ángulo, con el cual no cuenta el antecedente mostrado. Asimismo, la función principal de este producto es la comparación dentro de lo que respecta a las presiones plantares; entre la extremidad sana y la extremidad amputada. Estos datos son trasladados a una aplicación que brinda la información al personal médico y al paciente. La información principal que se busca encontrar es una comparativa entre las fuerzas de los pies; buscando que estas sean similares, pues de lo contrario, esto significaría que existe un desbalance, indicando de esta misma manera un indicio de desarrollo de alguna complicación médica. Mientras que la información de ángulo se centrará, principalmente, en el grado de libertad de la extremidad sana, para registrar los datos y evaluar que este no se vea afectado por el uso de la prótesis.

**	**

4. **VENTAJAS DE LA INVENCIÓN**

**Detalle** las ventajas que tiene la invención respecto a los antecedentes. Las ventajas podrían ser: mayor sensibilidad, especificidad, no presenta efectos secundarios, menor tiempo de diagnóstico, etc.

* **Integración sensor de ángulo:**

Los productos encontrados se enfocan principalmente en el estudio de la presión plantar, con la integración del MPU, se logra obtener una síntesis de información más completa y permite evaluar el proceso de adaptación del paciente con su prótesis; de manera que evalúa la libertad con la que las extremidades se pueden mover. Esto resulta crucial si buscamos analizar las consecuencias de la prótesis en la calidad de vida del paciente.

* **Modelo tipo tobillera:**

Los componentes electrónicos están almacenados y se encuentran en un estilo de tobillera, la cual brinda una mayor estabilidad para la adherencia de los sensores y permite poner el sensor MPU en la posición deseada.

* **Comunicación vía aplicación:**

El microprocesador utilizado es un ESP32 el cual nos permite el manejo de datos por vía bluetooth y la posterior integración de ellos por  medio de una aplicación. La ventaja que nosotros planteamos es el uso de la información en la telemedicina, para llevar un registro de los parámetros mencionados.

* **Intuitividad:**

El modo de uso es bastante intuitivo y permite que el usuario pueda hacer uso del producto independientemente. Es decir, no es necesario que cuente con ayuda de personal de salud al ponerse la tobillera. Esto nos permite realizar el estudio o evaluación remotamente.

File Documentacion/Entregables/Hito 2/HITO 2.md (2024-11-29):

image alt text

image alt text

image alt text

image alt text

image alt text

image alt text

image alt text

image alt text

image alt text

image alt text

image alt text

image alt text

image alt text

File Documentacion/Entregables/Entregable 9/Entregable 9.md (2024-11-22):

image alt textimage alt textimage alt text

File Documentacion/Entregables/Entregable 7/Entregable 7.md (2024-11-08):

**Vista del ensamble 3D:**

image alt text

**Diagrama de Flujo de Datos:**

Este esquema realiza una representación de los pasos que serán ejecutados por los componentes electrónicos, así como los datos que serán obtenidos a través de ellos.

image alt textº

Planos:

image alt textimage alt textimage alt textimage alt textimage alt text

Electrónica:

FSR402

image alt text
Codigo:
[https://github.com/lucasdmr24/Funbio-Proyecto/blob/main/Documentacion/Entregables/Entregable%207/FSR402.md](https://github.com/lucasdmr24/Funbio-Proyecto/blob/main/Documentacion/Entregables/Entregable%207/FSR402.md)

MPU6050
image alt text
Código:
[https://github.com/lucasdmr24/Funbio-Proyecto/blob/main/Documentacion/Entregables/Entregable%207/MPU4050.md](https://github.com/lucasdmr24/Funbio-Proyecto/blob/main/Documentacion/Entregables/Entregable%207/MPU4050.md)

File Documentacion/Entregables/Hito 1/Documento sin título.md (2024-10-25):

image alt textimage alt textimage alt textimage alt textimage alt textimage alt textimage alt textimage alt textimage alt textimage alt textimage alt textimage alt textimage alt textimage alt textimage alt textimage alt text

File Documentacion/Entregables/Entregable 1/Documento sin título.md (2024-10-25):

image alt textimage alt textimage alt textimage alt textimage alt textimage alt textimage alt textimage alt textimage alt textimage alt textimage alt textimage alt text

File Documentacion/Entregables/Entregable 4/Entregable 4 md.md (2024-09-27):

image alt textimage alt textimage alt textimage alt textimage alt textimage alt textimage alt textimage alt textimage alt textimage alt textimage alt textimage alt text

image alt text

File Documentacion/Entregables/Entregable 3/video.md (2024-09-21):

# Link para el video del entregable 3
https://drive.google.com/file/d/1zSCkVB_77PJCehVLOyyz3AAyu4dtfYEk/view?usp=sharing

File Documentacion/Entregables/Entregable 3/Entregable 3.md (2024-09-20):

1. **Problemática **

1. *Contexto:*

* Las amputaciones de miembros inferiores (tipo AK) afectan y disminuyen significativamente la calidad de vida de pacientes que padecen de diabetes mellitus. Sus capacidades sociales y económicas dejan de ser iguales a las de una persona sana, lo cual puede llegar a afectar a los pacientes también en un ámbito psicológico. 

* La relevancia de esto se relaciona de forma directa con la ingeniería biomédica ya que, mediante el desarrollo de prótesis y otros dispositivos médicos (de terapia y monitoreo) se puede lograr una mejora en la calidad de vida de estas personas, ayudándoles a que su reinserción social sea más rápida y sencilla.

2. *Definición del Problema*

* Debido a la falta de supervisión a un adulto amputado de miembro inferior (AK F2) durante la fase prostética, pueden producirse complicaciones como debilidad muscular, contracciones y deformidades, lo que aumenta la carga sobre la extremidad intacta. Las necesidades propias de cada paciente no son tomadas en cuenta, como la vuelta a la vida laboral y la frustración emocional del paciente por la dependencia prolongada o la adaptación a las prótesis, que podrían haberse evitado si hubieran recibido una supervisión adecuada.

3. *Impacto*

* Afecta directamente a los pacientes, puesto que sus capacidades motoras, sociales (dependencia) y económicas (tardan o no logran reincorporarse al mundo laboral) se ven claramente sesgadas debido a la amputación. 

* La esperanza de vida de los pacientes se reduce significativamente dentro de los primeros meses, hasta de 2 a 5 años después de la amputación en pacientes diabéticos (las enfermedades renales también afectan al aumento de la mortalidad en los pacientes).

* En los casos de amputaciones traumáticas, los empleadores de los pacientes también son afectados debido a que pierden a sus trabajadores de forma inesperada y se ven en la necesidad de buscar reemplazos en plazos cortos de tiempo.

* Los cupos de rehabilitación y terapias se ven saturados debido a la gran cantidad de pacientes que necesitan de estos servicios, y muchas veces los pacientes en situaciones económicas complicadas no logran alcanzar estos cupos, lo que afecta negativamente su proceso de rehabilitación.

2. **Propuesta de solución **

1. *Descripción de Solución:*

* Sistema de baropodometría en donde se pueda realizar este estudio a través del uso de plantillas integradas con sensores de presión y de medición de ángulo de la pisada. 

* Aborda la problemática a través del periodo protésico de la paciente; es decir, influye directamente en el proceso de seguimiento del usuario una vez que este haya recibido su prótesis definitiva. El objetivo principal de este estudio (baropodometría) y nuestro producto es tener un reporte de la distribución de peso y fuerza en las extremidades inferiores de la paciente con el fin de realizar una comparación entre ambas y evitar posibles afectaciones futuras ante una distribución desigual.

2. *Características del Prototipo* 

* Medir: Debe ser capaz de medir el ángulo del pie no amputado, con el fin de llevar a cabo un seguimiento en donde se identifique la susceptibilidad que este tiene con la prótesis y evitar cambios drásticos que terminen por afectar el equilibrio del paciente.

* Sensar: Debe ser capaz de sensar las fuerzas y distribución de ellas en distintos puntos de la planta del pie.

* Resistir: Debe ser capaz de resistir factores como el peso y movimiento. El peso específicamente, puesto que al ser un producto que se sitúa en la planta del pie y con la finalidad principal de obtener datos de la fuerza, deberá soportarlas de la misma manera. Por otro lado, debe resistir o no verse comprometido con el movimiento, puesto que el usuario debe realizar ciertas actividades para el estudio.

* Almacenar: Debe ser capaz de almacenar la información tanto del ángulo del pie como de la distribución de fuerzas, teniendo en cuenta la recopilación de datos máximos, mínimos, etc.

*¿Qué aspectos del producto han sido incluidos para satisfacer la problemática identificada?*

* Los aspectos más relevantes son los sensores tanto de presión como de ángulo, con el fin de satisfacer las necesidades del usuario en la etapa de seguimiento. Se reconoce de la misma manera que existen cualidades con las que debe contar nuestro producto como la comodidad, la facilidad de usar (que sea intuitivo y fácil de entender), entre otros.

3. *Beneficios *

* Uno de los beneficios incluye la retroalimentación por medio de una aplicación tanto para el paciente como el responsable médico, con el fin de tener una evidencia de la progresión o cambios que se presenten en la distribución de peso y el ángulo de la pisada.

* En comparación con otros dispositivos existentes, la presión plantar y el ángulo de giro se presentan en un solo dispositivo. Esta función no suele presentarse en plantillas, sino en dispositivos de mayor tamaño y menor portabilidad.

* Ofrece mayor libertad al usuario de medir la presión plantar en actividades que realice con mayor frecuencia, es decir se puede hacer un contraste entre la caminata solicitada usualmente en un estudio de baropodometría y otras actividades regulares.

4. Viabilidad  Técnica:
Será necesario manejar sensores tanto de presión como de ángulo. Se menciona así, por ejemplo los sensores de tipo FSR, los cuales ayudan a cuantificar la compresión o peso que es ejercido. También, para la medición de ángulo se pueden identificar otros sensores como los giroscopios. Será necesario evaluar los puntos específicos en donde estos deben ubicarse con el fin de obtener la información que sea de mayor ayuda. También, se necesitarán conocimientos de programación y almacenamiento de datos para poder recopilar información y organizarla.

3. **Coherencia **

La propuesta solución elegida en base a nuestra problemática es un sistema de baropodometría con plantillas que incorporan sensores de presión y ángulo de pisada. Este incluye una aplicación para ofrecer retroalimentación continua entre paciente y médico. 

1. Contexto del Proyecto

¿Por qué la propuesta de solución elegida es necesaria en este caso?

Se considera que está propuesta es necesaria ya que un seguimiento adecuado durante la adaptación a la prótesis es crucial para evitar problemas como debilidad muscular y deformidades en la extremidad intacta por lo que se debe identificar y corregir estos problemas de manera temprana. Asimismo al ofrecer un monitoreo continuo se facilita una rehabilitación más efectiva y acelerar su reinserción laboral y social. La retroalimentación a través de una aplicación proporciona a los pacientes y a sus médicos información valiosa sobre su progreso, lo que aumenta la motivación y reduce la frustración emocional.

¿Cómo se integra con el entorno general de la ingeniería biomédica?

El diseño y creación de dispositivos como las plantillas con sensores son ejemplos de la aplicación de la ingeniería biomédica. Esto incluye la investigación en materiales, diseño ergonómico y la integración de tecnologías de medición. La capacidad de monitorear la presión plantar y el ángulo del pie se alinea con el enfoque biomédico en mejorar la salud y calidad de vida a través de la innovación en dispositivos médicos.

2. Objetivos del Proyecto

Desarrollar un sistema de baropodometría que permita un seguimiento efectivo de pacientes amputados de miembro inferior, mejorando su rehabilitación y calidad de vida tras la adaptación a prótesis. 

Cómo objetivos específicos se considera medir y analizar la distribución de peso, proporcionar datos precisos para el seguimiento clínico; monitorear el ángulo de la pisada, facilitar la identificación de cambios que puedan afectar el equilibrio y la movilidad del paciente; proveer retroalimentación en tiempo real, permite la comunicación efectiva entre pacientes y profesionales de la salud; y facilitar la adaptación a la prótesis y contribuir a la investigación.

3. Justificación del Prototipo 

La baropodometría se presenta como la solución alternativa más integral dentro de nuestros servicios, con un enfoque específico en la fase protésica. Esta técnica avanzada no solo optimiza la adaptación del paciente a la prótesis, sino que también permite mejorar la seguridad y comodidad al utilizarla. A través de la monitorización precisa de la distribución de las presiones plantares, es posible ajustar la prótesis de manera personalizada, facilitando su uso en la rutina diaria del paciente. De esta manera, se promueve la reintegración efectiva del usuario a la vida laboral, reduciendo su dependencia de terceros y garantizando un seguimiento continuo para optimizar su calidad de vida y bienestar a largo plazo.

4. Alineación con el Problema 

Nuestro prototipo se destaca por su capacidad de identificar el aumento de la carga sobre la extremidad sana, que suele derivarse del uso inadecuado de la prótesis. A través de un análisis detallado de la distribución de peso y fuerza en las extremidades inferiores, se realiza una comparación precisa entre ambas, lo que permite prevenir complicaciones comunes como debilidad muscular, contracturas y deformidades. Además, nuestro enfoque incluye un seguimiento personalizado mediante el uso de baropodometría, lo que facilita una adaptación más rápida y eficiente del paciente a la prótesis. Considerando aspectos fundamentales como el retorno a la vida laboral y el impacto emocional que puede generar una adaptación prolongada, nuestro sistema garantiza un monitoreo continuo y un ajuste personalizado que mejora la experiencia del paciente, minimizando la frustración y favoreciendo una reintegración más ágil y segura a sus actividades cotidianas.

4. **Resumen **

Las amputaciones de miembros inferiores en pacientes diabéticos generan complicaciones físicas, emocionales y económicas, afectando su calidad de vida y limitando su reinserción social y laboral. La falta de supervisión durante la fase protésica puede llevar a debilidad muscular y otros problemas, exacerbando la dependencia y la frustración del paciente.

Se propone un sistema de baropodometría que utiliza plantillas con sensores de presión y de medición del ángulo de la pisada. Este dispositivo permitirá un monitoreo continuo, prevención de complicaciones y acceso a datos.

Algunos puntos claves son la mejora de la rehabilitación, integración de funciones e impacto en la calidad de vida. Esta propuesta es crucial para abordar las necesidades específicas de los pacientes amputados, promoviendo su bienestar integral.

Se busca obtener un monitoreo efectivo de la distribución de peso y fuerzas en las extremidades inferiores de los pacientes amputados, facilitando una adaptación más rápida a las prótesis y mejorando su autonomía. Además, se pretende proporcionar a los médicos información continua sobre el progreso del paciente, permitiendo ajustes en el tratamiento y favoreciendo una reinserción social y laboral más efectiva.

El prototipo se someterá a pruebas de laboratorio para evaluar la funcionalidad y resistencia de los sensores. Posteriormente, se realizará un estudio con usuarios donde se recogerán datos sobre su uso en actividades diarias y se obtendrá retroalimentación para mejorar la usabilidad. Esto permitirá validar la efectividad del dispositivo y su impacto en la calidad de vida de los pacientes.

[https://raaot.org.ar/index.php/AAOTMAG/article/view/1592/5101#:~:text=El%20tiempo%20promedio%20hasta%20el,o%20infrarrotuliana%20(2.19%20a%C3%B1os).](https://raaot.org.ar/index.php/AAOTMAG/article/view/1592/5101#:~:text=El%20tiempo%20promedio%20hasta%20el,o%20infrarrotuliana%20(2.19%20a%C3%B1os).)

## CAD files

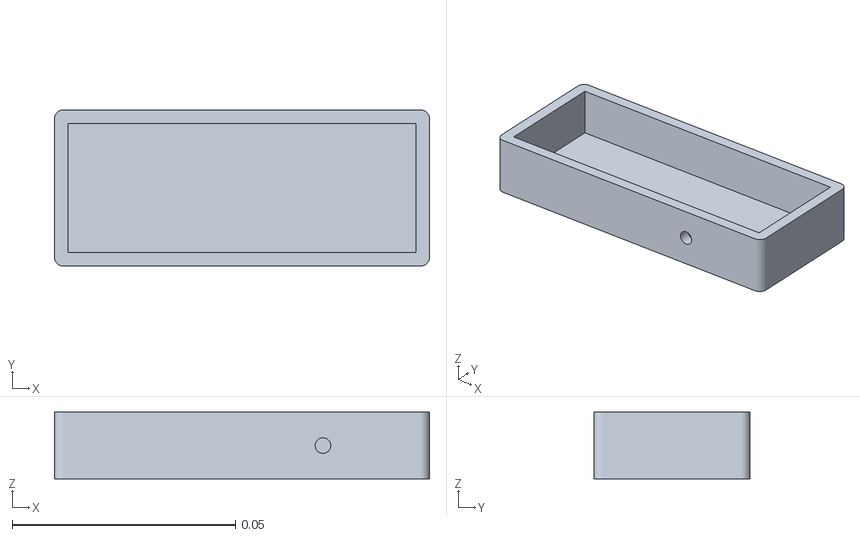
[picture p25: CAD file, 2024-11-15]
Documentacion/Hardware/Tapa Portapila.stl
0.084 x 0.035 x 0.015

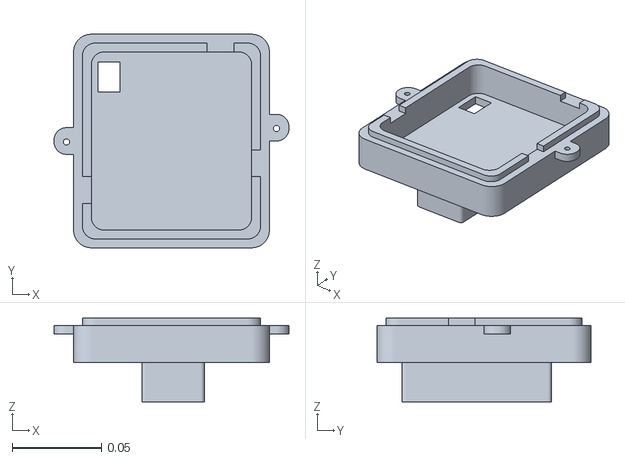
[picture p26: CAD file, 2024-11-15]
Documentacion/Hardware/Medidas case electronica superior.stl
0.132 x 0.12 x 0.047

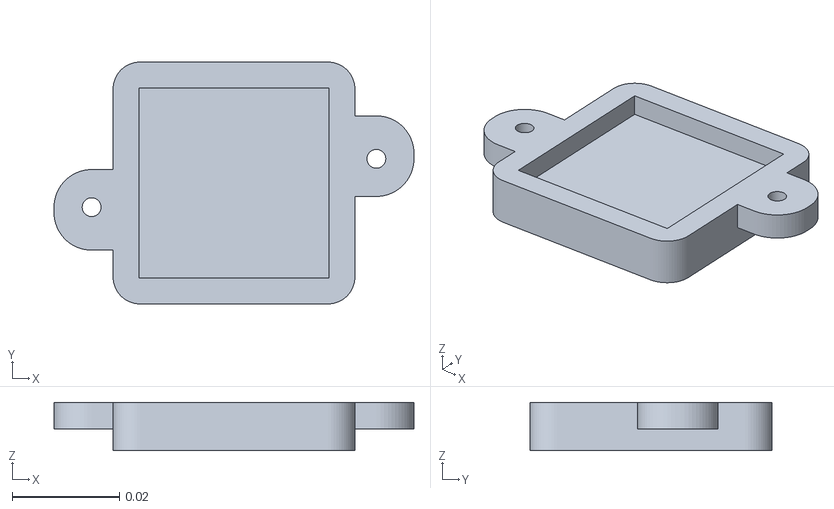
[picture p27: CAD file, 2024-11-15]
Documentacion/Hardware/Case MPU inferior.stl
0.067 x 0.045 x 0.009

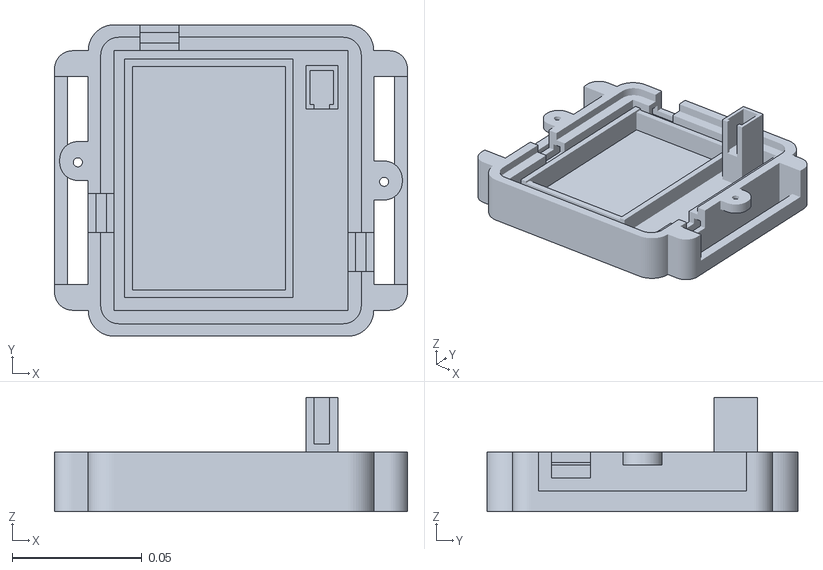
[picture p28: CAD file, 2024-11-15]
Documentacion/Hardware/Medidas case electronica inferior.stl
0.136 x 0.12 x 0.044

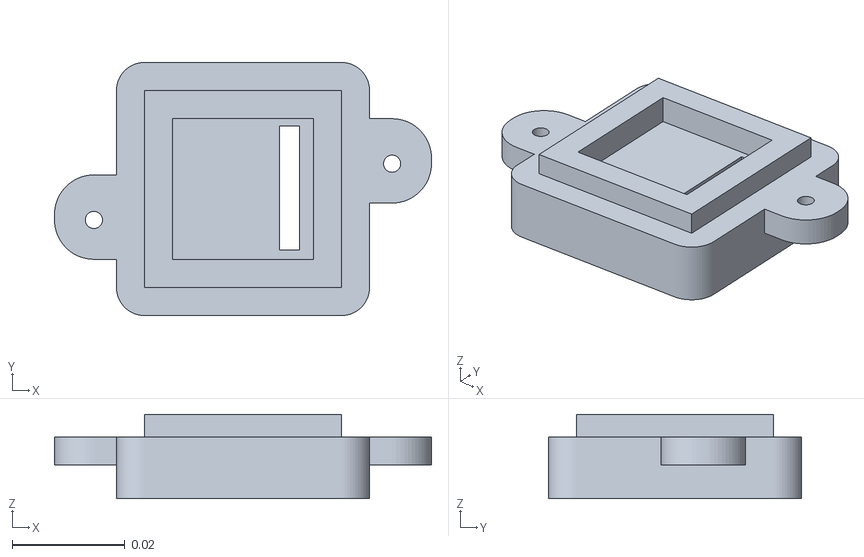
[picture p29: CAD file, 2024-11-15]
Documentacion/Hardware/Case MPU superior.stl
0.067 x 0.045 x 0.015
